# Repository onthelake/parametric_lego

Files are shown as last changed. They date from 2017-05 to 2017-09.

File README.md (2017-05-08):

# Parametric LEGO #

### 3D Printable LEGO shapes with fine-tuning parameters for a tight fit with different materials ###

Print out snap-together cases and objects by starting from a proper LEGO part. Making LEGO-compatibible boxes and enclosures is one of the motivations for this project. See for example https://github.com/paulirotta/lego_grove

### Who do I talk to? ###

* paulirotta@gmail.com
* https://twitter.com/mobile_rat
* https://medium.com/@paulhoughton
* https://github.com/paulirotta/parametric_lego/

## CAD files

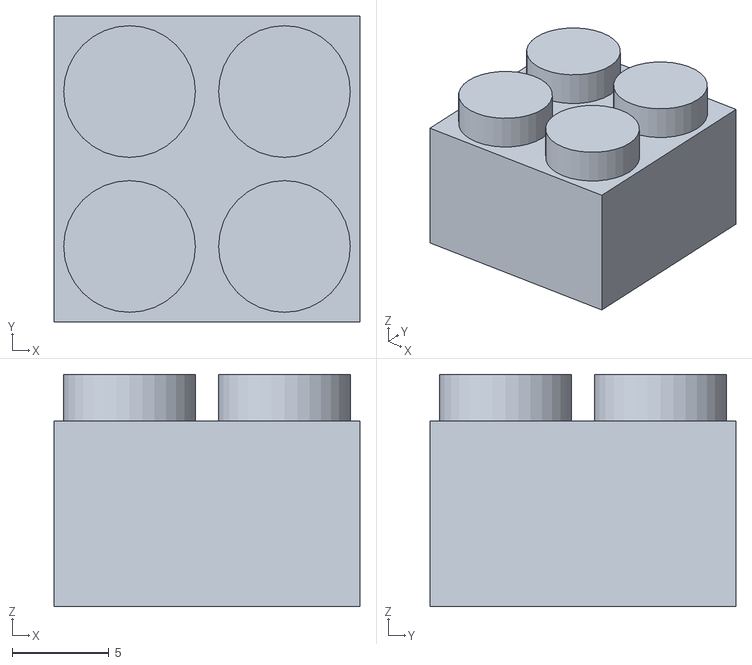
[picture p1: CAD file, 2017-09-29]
lego-abs-2x2x1.stl
15.8 x 15.8 x 12.0

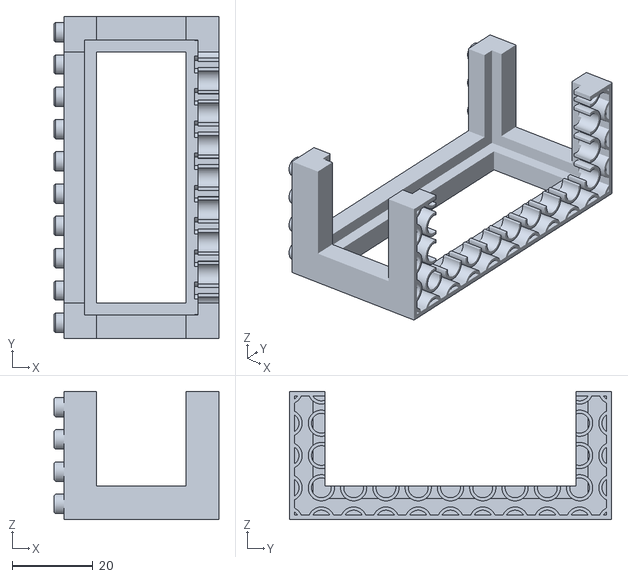
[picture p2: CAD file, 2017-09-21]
lego-enclosure/lego-enclosure-abs.stl
40.8 x 79.8 x 31.8

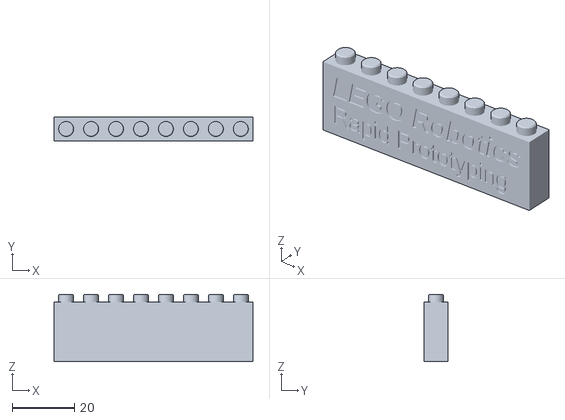
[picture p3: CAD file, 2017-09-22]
lego-sign/lego-sign-etched-abs.stl
63.8 x 7.80 x 21.6

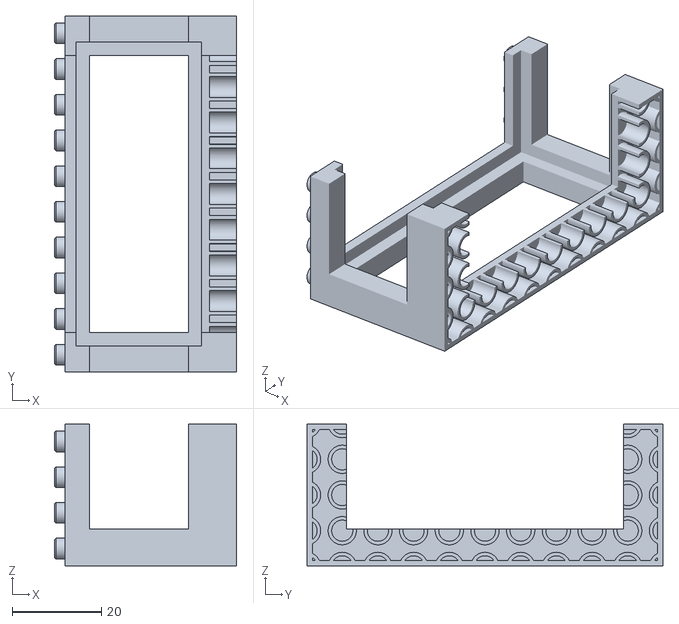
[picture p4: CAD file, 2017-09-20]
lego-enclosure/lego-enclosure-ngen.stl
40.8 x 79.8 x 31.8

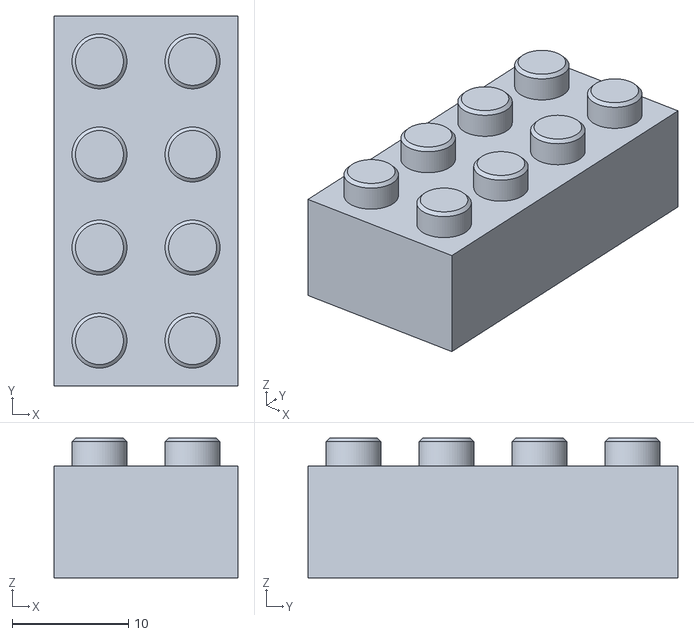
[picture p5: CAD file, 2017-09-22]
lego-pla-2x4x1.stl
15.8 x 31.8 x 12.0

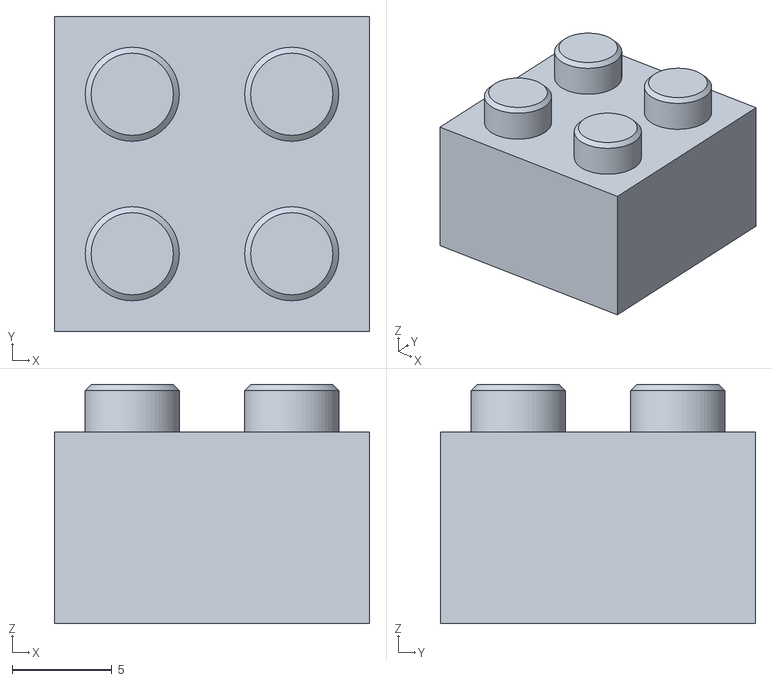
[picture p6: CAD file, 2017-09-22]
lego-pla-2x2x1.stl
15.8 x 15.8 x 12.0

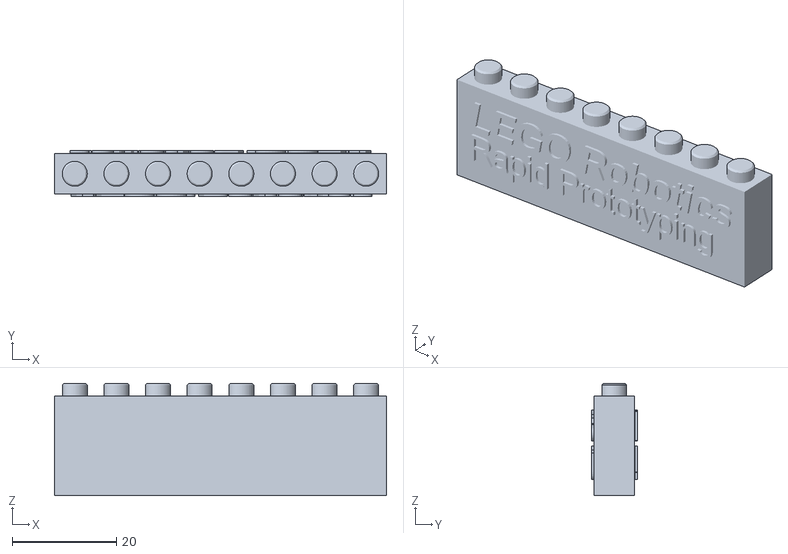
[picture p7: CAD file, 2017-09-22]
lego-sign/lego-sign-two-sided-abs.stl
63.8 x 8.90 x 21.6

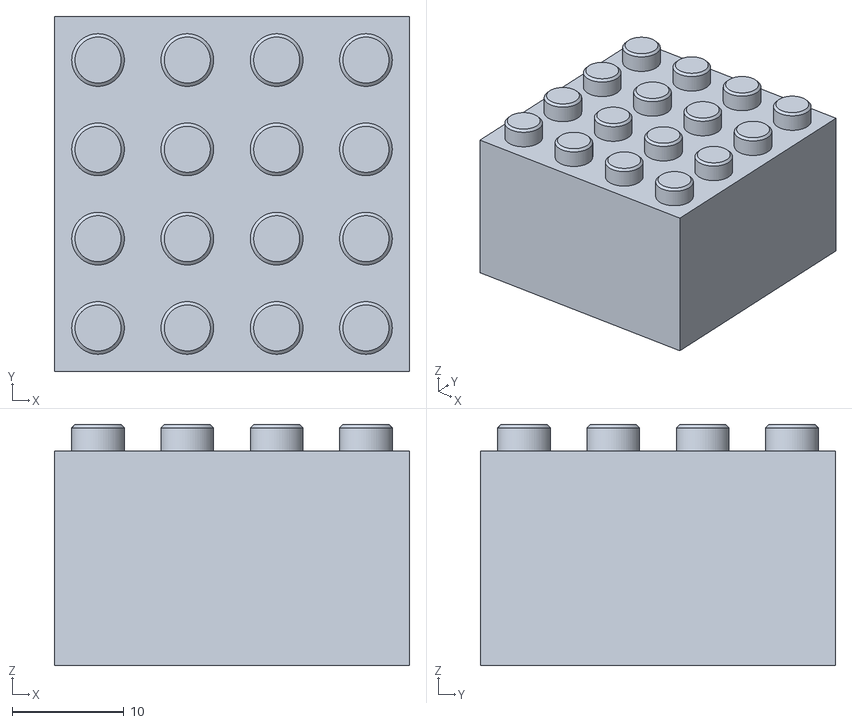
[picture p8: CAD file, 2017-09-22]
lego-pla-4x4x2.stl
31.8 x 31.8 x 21.6

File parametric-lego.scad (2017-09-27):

/*
Parametric LEGO Block

Published at
    http://www.thingiverse.com/thing:2303714
Maintained at
    https://github.com/paulirotta/parametric_lego
See also the related files
    LEGO Sign Generator - https://www.thingiverse.com/thing:2546028
    LEGO Enclosure Generator - https://www.thingiverse.com/thing:2544197


By Paul Houghton
Twitter: @mobile_rat
Email: paulirotta@gmail.com
Blog: https://medium.com/@paulhoughton

Creative Commons Attribution ShareAlike NonCommercial License
    https://creativecommons.org/licenses/by-sa/4.0/legalcode

Work sponsored by
    http://futurice.com

Import this into other design files:
    use <lego.scad>
*/

/* [LEGO Options plus Plastic and Printer Variance Adjustments] */

// What type of object to generate: "lego", "calibration", "panel"
mode="panel";

// How many Lego units wide the brick is
blocks_x = 15;

// How many Lego units long the brick is
blocks_y = 11;

// How many Lego units high the brick is
blocks_z = 1;


// Top connector size tweak => + = more tight fit, -0.04 for PLA, 0 for ABS, 0.07 for NGEN
top_tweak = 0.07;

// Bottom connector size tweak => + = more tight fit, 0.02 for PLA, 0 for ABS, -0.01 NGEN
bottom_tweak = -0.01;

// Number of facets to form a circle (big numbers are more round which affects fit, but may take a long time to render)
fn=64;

// Clearance space on the outer surface of bricks
skin = 0.1;

// Size of the connectors
knob_radius=2.4;

// Height of the connectors including any bevel (1.8 is Lego standard, longer gives a stronger hold which helps since 3D prints are less precise)
knob_height=2.4;

// Height of the easy connect slope near connector top (0 to disable is standard a slightly faster to generate the model, a bigger value such as 0.3 may help if you adjust a tight fit but most printers' slicers will simplify away most usable bevels)
knob_bevel=0;

// Size of the small cavity inside the connectors
knob_cutout_radius=1.25;

// Distance below knob top surface and the internal cutout
knob_top_thickness=1.25;

// Height of the cutout beneatch each knob
knob_cutout_height=4.35;

// Size of the hole to keep the cutout as part of the outside surface for slicer-friendliness. Enlarge this if you need to drain resin from the cutout.
knob_cutout_airhole_radius=0.01;

// Depth which connectors may press into part bottom
socket_height=6;

// Bottom connector assistance ring size
ring_radius=3.25;

// Bottom connector assistance ring thickness
ring_thickness=0.8;

// Basic unit horizonal size of LEGO
block_width=8;

// Basic unit vertial size of LEGO
block_height=9.6;

// Thickness of the solid outside surface of LEGO
block_shell=1.3; // thickness

// Lego panel height (flat back panel with screw holes in corners
cut_line=6.4;

// Font for calibration block text labels
font = "Arial";

// Text size on calibration blocks
font_size = 3.8;

// Depth of text labels on calibration blocks
text_extrusion_height = 0.5;

// Inset from block edge for text (vertical and horizontal)
text_margin = 1;

// Size between calibration block tweak test steps
calibration_block_increment = 0.01;

/////////////////////////////////////
// Test display, uncomment only one of the following lines at a time
/////////////////////////////////////

if (mode=="calibration") {
    lego_calibration_set(); // A set of blocks for testing which tweak parameters to use on your printer and plastic
} else if (mode=="panel") {
    lego_panel(); // A thin panel of knobs with a flat back and mounting screw holes in the corners, suitable for organizing projects
} else {
    lego(); // A single block
}

/////////////////////////////////////
// FUNCTIONS
/////////////////////////////////////

// Function for access to horizontal size from other modules
function lego_width(x=1) = x*block_width;

// Function for access to vertical size from other modules
function lego_height(z=1) = z*block_height;

// Function for access to outside shell size from other modules
function lego_shell_width() = block_shell;

// Function for access to clearance space from other modules
function lego_skin_width(i=1) = skin*i;

// Function for access to socket height from other modules
function lego_socket_height() = socket_height;

/////////////////////////////////////
// MODULES
/////////////////////////////////////

// A complete LEGO block, standard size, specify number of layers in X Y and Z
module lego(x=blocks_x, y=blocks_y, z=blocks_z, top_tweak=top_tweak, bottom_tweak=bottom_tweak, fn=fn) {
    difference() {
        union() {
            block_shell(x, y, z, fn);
            difference() {
                block_set(x, y, z, top_tweak, fn);
                socket_set(x, y, bottom_tweak, fn);
            }
        }
        skin(x, y, z);
    }
}


// Several blocks in a grid, one knob per block
module block_set(x=blocks_x, y=blocks_y, z=blocks_z, top_tweak=top_tweak, fn=fn) {
    for (i = [0:1:x-1]) {
        for (j = [0:1:y-1]) {
            translate([lego_width(i), lego_width(j), 0])
                block(z=z, top_size_tweak=top_tweak, knob_height=knob_height,knob_cutout_height=knob_cutout_height, knob_cutout_radius=knob_cutout_radius, knob_cutout_airhole_radius=knob_cutout_airhole_radius, fn=fn);
        }
    }
}


// The rectangular part of the the lego plus the knob
module block(z=bocks_z, top_tweak=top_tweak, knob_height=knob_height, knob_cutout_height=knob_cutout_height, knob_cutout_radius=knob_cutout_radius, knob_cutout_airhole_radius=knob_cutout_airhole_radius, fn=fn) {
    difference() {
        union() {
            cube([lego_width(), lego_width(), lego_height(z)]);
            translate([lego_width(0.5), lego_width(0.5), lego_height(z)])
                knob(top_tweak=top_tweak, knob_bevel=knob_bevel, fn=fn);
        }
        translate([lego_width(0.5), lego_width(0.5), lego_height(z)])
            knob_cutout(knob_height=knob_height, knob_cutout_height=knob_cutout_height, knob_cutout_radius=knob_cutout_radius, knob_cutout_airhole_radius=knob_cutout_airhole_radius, fn=fn);
    }
}


// The cylinder on top of a lego block
module knob(top_tweak=top_tweak, knob_bevel=knob_bevel, fn=fn) {
    cylinder(r=knob_radius+top_tweak, h=knob_height-knob_bevel, $fn=fn);
    if (knob_bevel > 0) {
        // This path is a bit slower, but does the same thing as the bath below for the most common case of knob_bevel==0
        translate([0, 0, knob_height-knob_bevel])
            intersection() {
                cylinder(r=knob_radius+top_tweak,h=knob_bevel, $fn=fn);
                cylinder(r1=knob_radius+top_tweak,r2=0,h=knob_radius+top_tweak, $fn=fn);
            }
    }
}


// The empty cylinder inside a knob
module knob_cutout(knob_height=knob_height, knob_cutout_height=knob_cutout_height, knob_cutout_radius=knob_cutout_radius, knob_cutout_airhole_radius=knob_cutout_airhole_radius, fn=fn) {
    cylinder(r=knob_cutout_airhole_radius, h=knob_height+0.1, $fn=fn);
    translate([0, 0, knob_height-knob_top_thickness-knob_cutout_height])
        cylinder(r=knob_cutout_radius, h=knob_cutout_height, $fn=fn);
}


// That solid outer skin of a block set
module block_shell(x=blocks_x, y=blocks_y, z=blocks_z) {
    cube([block_shell, lego_width(y), lego_height(z)]);
    translate([lego_width(x)-block_shell, 0, 0]) 
        cube([block_shell, lego_width(y), lego_height(z)]);
    
    cube([lego_width(x), block_shell, lego_height(z)]);
    translate([0, lego_width(y)-block_shell, 0])
        cube([lego_width(x), block_shell, lego_height(z)]);
    
    translate([0, 0, lego_height(z)-block_shell])
        cube([lego_width(x), lego_width(y), block_shell]);
}

// Bottom connector- negative space for one block
module socket(bottom_tweak=bottom_tweak, fn=fn) {
    difference() {
        cube([lego_width(), lego_width(), socket_height]);
        union() {
            socket_ring(bottom_tweak, fn);
            translate([lego_width(), 0, 0])
                socket_ring(bottom_tweak, fn);
            translate([0, lego_width(), 0]) 
                socket_ring(bottom_tweak, fn);
            translate([lego_width(), lego_width(), 0])
                socket_ring(bottom_tweak, fn);
        }
    }
}

// The circular bottom insert for attaching knobs
module socket_ring(bottom_tweak=bottom_tweak, fn=fn) {
    difference() {
        cylinder(r=ring_radius+bottom_tweak, h=socket_height, $fn=fn);
        cylinder(r=ring_radius+bottom_tweak-ring_thickness, h=socket_height, $fn=fn);
    }
}

// Bottom connector- negative space for multiple blocks
module socket_set(x=blocks_x, y=blocks_y, bottom_tweak=bottom_tweak, fn=fn) {
    for (i = [0:1:x-1]) {
        for (j = [0:1:y-1]) {
            translate([lego_width(i), lego_width(j), 0])
                socket(bottom_tweak, fn);
        }
    }
}
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

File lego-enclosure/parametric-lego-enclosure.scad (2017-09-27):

/*
Parametric LEGO End Cap Enclosure Generator

Create 2 symmetric end pieces which can support a solid object with LEGO-compatible attachment points on top and bottom. By printing only the end pieces instead of a complele enclosure, the print is minimized

Published at
    https://www.thingiverse.com/thing:2544197
Based on
    https://www.thingiverse.com/thing:2303714
Maintained at
    https://github.com/paulirotta/parametric_lego

By Paul Houghton
Twitter: @mobile_rat
Email: paulirotta@gmail.com
Blog: https://medium.com/@paulhoughton

Creative Commons Attribution ShareAlike NonCommercial License
    https://creativecommons.org/licenses/by-sa/4.0/legalcode

Work sponsored by
    http://futurice.com

Import this into other design files:
    use <anker-usb-lego-enclosure.scad>
*/

use <../lego.scad>

/* [LEGO Options plus Plastic and Printer Variance Adjustments] */

// How many Lego units wide the enclosure is
blocks_x = 23;

// How many Lego units long the enclosure is
blocks_y = 10;

// How many Lego units long is the enclosure holder
blocks_x_end_cap = 4;

// How many Lego units high the enclosure is
blocks_z = 4;

// Length of the object to be enclosed
enclosed_length = 173;

// Width of the object to be enclosed
enclosed_width = 68;

// Height of the object to be enclosed
enclosed_height = 28;

// Top connector size tweak => + = more tight fit, -0.04 for PLA, 0 for ABS, 0.07 for NGEN
top_tweak = 0;

// Bottom connector size tweak => + = more tight fit, 0.02 for PLA, 0 for ABS, -0.01 NGEN
bottom_tweak = 0;

// Number of facets to form a circle (big numbers are more round which affects fit, but may take a long time to render)
fn = 64;

// The size of the step in each corner which supports the enclosed part while providing ventilation holes to remove heat
shoulder = 3;

/////////////////////////////////////

// Test display
rotate([0,-90,0])
    lego_enclosure(top_tweak=top_tweak, bottom_tweak=bottom_tweak);

///////////////////////////////////


// A Lego brick with a hole inside to contain something of the specified dimensions
module lego_enclosure(l=enclosed_length, w=enclosed_width, h=enclosed_height, x=blocks_x, x_cap=blocks_x_end_cap, y=blocks_y, z=blocks_z, shoulder=shoulder, top_tweak=top_tweak, bottom_tweak=bottom_tweak, fn=fn) {
    
    // Add some margin to give space to fit the part
    skinned_l = l + lego_skin_width(2);
    skinned_w = w + lego_skin_width(2);
    skinned_h = h + lego_skin_width(2);
    
    // Inner box dimensions
    dl=(lego_width(x)-skinned_l)/2;
    dw=(lego_width(y)-skinned_w)/2;
    dh=(lego_height(z)-skinned_h)/2;
    
    difference() {
        lego(x=x_cap, y=y, z=z, top_tweak=top_tweak, bottom_tweak=bottom_tweak, fn=fn);
        translate([dl, dw, dh])
            enclosure_negative_space(skinned_l, skinned_w, skinned_h, shoulder);
    }
}

// Where to remove material to privide access for attachments and air ventilation
module enclosure_negative_space(l=enclosed_length, w=enclosed_width, h=enclosed_height, shoulder=shoulder) {
    ls = l - 2*shoulder;
    ws = w - 2*shoulder;
    hs = h - 2*shoulder;
    ls2 = ls+l;
    ws2 = ws+w;
    hs2 = hs+h;
    
    // Primary enclosure hole
    cube([l, w, h]);
    
    // Right air hole
    translate([l, shoulder, shoulder])
        cube([ls2, ws, hs]);
    
    // Left air hole
    translate([-ls2, shoulder, shoulder])
        cube([ls2, ws, hs]);
    
    // Back air hole
    translate([shoulder, w, shoulder])
        cube([ls, ws2, hs]);
        
    // Front air hole
    translate([shoulder, -ws2, shoulder])
        cube([ls, ws2, hs]);
        
    // Top air hole
    translate([shoulder, shoulder, h])
        cube([ls, ws, hs2]);
        
    // Bottom air hole
    translate([shoulder, shoulder, -hs2])
        cube([ls, ws, hs2]);
}

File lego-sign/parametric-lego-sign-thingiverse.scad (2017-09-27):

/*
Parametric LEGO End Cap Enclosure Generator

Create 2 symmetric end pieces which can support a solid object with LEGO-compatible attachment points on top and bottom. By printing only the end pieces instead of a complele enclosure, the print is minimized

Published at
    https://www.thingiverse.com/thing:2546028
Based on
    https://www.thingiverse.com/thing:2303714
Maintained at
    https://github.com/paulirotta/parametric_lego

By Paul Houghton
Twitter: @mobile_rat
Email: paulirotta@gmail.com
Blog: https://medium.com/@paulhoughton

Creative Commons Attribution ShareAlike NonCommercial License
    https://creativecommons.org/licenses/by-sa/4.0/legalcode

Work sponsored by
    http://futurice.com

Import this into other design files:
    use <parametric-lego-sign.scad>
    
NOTE: The online Thingiverse customizer does not support boolean variables, so
these variables have been changed to strings
*/

/* [LEGO Options plus Plastic and Printer Variance Adjustments] */

// The top line of text. Set to "" to not have any top line
text_line_1 = "LEGO Robotics";

// The second line of text
text_line_2 = "Rapid Prototyping";

// Language of the text
text_language = "en";

// The font to use for text on the top line
font_line_1 = "Liberation Sans:style=Bold Italic";

// The font to use for text on the bottom line
font_line_2 = "Arial";

// The font size (points) of the top line
font_size_line_1 = 5.8;

// The font size (points) of the top line
font_size_line_2 = 5;

// How deeply into the LEGO block to etch/extrude the text
text_extrusion_height = 0.5;

// Text is pushing out from the LEGO block. Set false to etch the text into the block
extrude = "false";

// Place the text on both sides
copy_to_back = "false";

// How many LEGO units wide the enclosure is
blocks_x = 8;

// How many LEGO units long the enclosure is
blocks_y = 1;

// How many LEGO units high the enclosure is
blocks_z = 2;

// Left corner horizontal position of the text
text_x_inset = 3;

// Bottom / top corner vertical position of the text
text_z_inset = 3;

// Top connector size tweak => + = more tight fit, -0.04 for PLA, 0 for ABS, 0.07 for NGEN
top_connector_tweak = 0;

// Bottom connector size tweak => + = more tight fit, 0.02 for PLA, 0 for ABS, -0.01 NGEN
bottom_connector_tweak = 0;

// Number of facets to form a circle (big numbers are more round which affects fit, but may take a long time to render)
rounding=32;

/////////////////////////////////////

// Test display
lego_sign();

///////////////////////////////////

// A LEGO brick with text on the side
module lego_sign(line_1=text_line_1, line_2=text_line_2, lang=text_language, e=extrude,  extrusion_height=text_extrusion_height, f1=font_line_1, f2=font_line_2, fs1=font_size_line_1, fs2=font_size_line_2, tx=text_x_inset, tz=text_z_inset, xb=blocks_x, yb=blocks_y, zb=blocks_z, bottom_size_tweak=bottom_connector_tweak, top_size_tweak=bottom_connector_tweak, fn=rounding) {
    if (e == "true") {
        lego(x=xb, y=yb, z=zb, bottomw_connector_tweak=bottom_size_tweak, top_connector_tweak=top_size_tweak, fn=fn);
        translate([lego_skin_width(), lego_skin_width(), lego_skin_width()])
            lego_sign_extruded_text(line_1, line_2, lang, extrusion_height, f1, f2, fs1, fs2, tx, tz, xb, yb, zb, bottom_size_tweak, top_size_tweak, fn);

        if (copy_to_back == "true") {
            translate([lego_skin_width()+lego_width(xb), lego_width(yb), lego_skin_width()])
                rotate([0, 0, 180])
                    lego_sign_extruded_text(line_1, line_2, lang, extrusion_height, f1, f2, fs1, fs2, tx, tz, xb, yb, zb, bottom_size_tweak, top_size_tweak, fn);
        }
    } else {
        difference() {
            lego(x=xb, y=yb, z=zb, bottom_connector_tweak=bottom_size_tweak, top_connector_tweak=top_size_tweak, fn=fn);
            union() {
                translate([lego_skin_width(), 0, lego_skin_width()])
                    lego_sign_etched_text(line_1, line_2, lang, extrusion_height+lego_skin_width(), f1, f2, fs1, fs2, tx, tz, xb, yb, zb, bottom_size_tweak, top_size_tweak, fn);

                    if (copy_to_back == "true") {
                         translate([lego_skin_width()+lego_width(xb), lego_skin_width()+lego_width(yb), lego_skin_width()])
                             rotate([0, 0, 180])
                                 lego_sign_etched_text(line_1, line_2, lang, extrusion_height+lego_skin_width(), f1, f2, fs1, fs2, tx, tz, xb, yb, zb, bottom_size_tweak, top_size_tweak, fn);
                    }
                }
            }
    }
}

// Two lines of text extruded out from the surface
module lego_sign_extruded_text(line_1=text_line_1, line_2=text_line_2, lang=text_language,  extrusion_height=text_extrusion_height, f1=font_line_1, f2=font_line_2, fs1=font_size_line_1, fs2=font_size_line_2, tx=text_x_inset, tz=text_z_inset, xb=blocks_x, yb=blocks_y, zb=blocks_z, bottom_size_tweak=bottom_connector_tweak, top_size_tweak=bottom_connector_tweak, fn=rounding) {
    translate([tx, 0, lego_height(zb)-tz])
        lego_text(txt=line_1, language=lang, font=f1, font_size=fs1, vertical_alignment="top");
    translate([tx, 0, tz])
        lego_text(txt=line_2, language=lang, font=f2, font_size=fs2, vertical_alignment="bottom");
}

// Two lines of text etched into the surface
module lego_sign_etched_text(line_1=text_line_1, line_2=text_line_2, lang=text_language,  extrusion_height=text_extrusion_height, f1=font_line_1, f2=font_line_2, fs1=font_size_line_1, fs2=font_size_line_2, tx=text_x_inset, tz=text_z_inset, xb=blocks_x, yb=blocks_y, zb=blocks_z, bottom_size_tweak=bottom_connector_tweak, top_size_tweak=bottom_connector_tweak, fn=rounding) {
    translate([tx, extrusion_height, lego_height(zb)-tz])
        lego_text(txt=line_1, l=lang, extrusion_height=extrusion_height, font=f1, font_size=fs1, vertical_alignment="top");
    translate([tx, extrusion_height, tz])
        lego_text(txt=line_2, l=lang, extrusion_height=extrusion_height, font=f2, font_size=fs2, vertical_alignment="baseline");
}

// Text for the side of calibration block prints
module lego_text(txt=text_line_1, l=text_language, extrusion_height=text_extrusion_height, font=font_line_1, font_size=font_size_line_1, vertical_alignment="bottom") {
    rotate([90,0,0])
        linear_extrude(height=extrusion_height)
            text(text=txt, language=l, font=font, size=font_size, halign="left", valign=vertical_alignment);
}



////// Partial copy of file lego.scad to make this a single file for use in thingiverse.com online generator

// Clearance space on the outer surface of bricks
skin = 0.1;

// Size of the connectors
knob_radius=2.4;

// Total height of the connectors (1.8 is Lego standard, longer gives a stronger hold which helps since 3D prints are less precise)
knob_height=2.4;

// Height of the easy connect slope near connector top (0 to disable, helps if you adjust a tight fit)
knob_bevel=0.3;

// Depth which connectors may press into part bottom
socket_height=6;

// Bottom connector assistance ring size
ring_radius=3.25;

// Bottom connector assistance ring thickness
ring_thickness=0.8;

// Basic unit horizonal size of LEGO
block_width=8;

// Basic unit vertial size of LEGO
block_height=9.6;

// Thickness of the solid outside surface of LEGO
block_shell=1.3; // thickness


/////////////////////////////////////

// The round bit on top of a lego block
module knob(top_size_tweak=0, fn=rounding) {
    $fn = fn;
    cylinder(r=knob_radius+top_size_tweak,h=knob_height-knob_bevel);
    translate([0,0,knob_height-knob_bevel]) 
        intersection() {
            cylinder(r=knob_radius+top_size_tweak,h=knob_bevel);
            cylinder(r1=knob_radius+top_size_tweak,r2=0,h=knob_radius+top_size_tweak);
        }
}

// The rectangular part of the the lego plus the knob
module block(z=1, top_size_tweak=0, fn=rounding) {
    cube([block_width,block_width,z*block_height]);
    translate([block_width/2,block_width/2,z*block_height])
        knob(top_size_tweak, fn);
}

// Several blocks in a grid, one knob per block
module block_set(x=2, y=2, z=2, top_size_tweak=0, fn=rounding) {
    for (i = [0:1:x-1]) {
        for (j = [0:1:y-1]) {
            translate([i*block_width,j*block_width,0])
                block(z, top_size_tweak, fn);
        }
    }
}

// That solid outer skin of the block set
module block_shell(x=2, y=2, z=2) {
    cube([block_shell,y*block_width,z*block_height]);
    translate([x*block_width-block_shell,0,0]) 
        cube([block_shell,y*block_width,z*block_height]);
    
    cube([x*block_width,block_shell,z*block_height]);
    translate([0,y*block_width-block_shell,0])
        cube([x*block_width,block_shell,z*block_height]);
    
    translate([0,0,z*block_height-block_shell])
        cube([x*block_width,y*block_width,block_shell]);
}
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

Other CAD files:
lego-sign/lego-sign-etched-ngen.stl
lego-enclosure/lego-enclosure-pla.stl
lego-sign/lego-sign-two-sided-ngen.stl
lego-ngen-2x4x1.stl
lego-sign/lego-sign-two-sided-pla.stl
lego-ngen-4x4x2.stl
lego-sign/lego-sign-etched-pla.stl
lego-ngen-2x2x1.stl
command-line-lego.scad
lego-sign/lego-sign.scad
lego.scad

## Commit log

2017-05-08 Comment updates
    [lego.scad]
2017-09-18 Added LEGO calibration block set for testing the parameters needed on a given printer and plastic to get a tight fit Added LEGO panel builder with corner screw holes Minor updates and tweaks Changed 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
    [lego-abs-2x2x1.stl, lego-abs-2x4x1.stl, lego-abs-4x4x2.stl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]
2017-09-19 Changed generic inner enclosure directory References to upper dir <lego.scad> Passing $fn as an argument into lego modules Enclosure now builds as an end
    TODO The skins on the bottom are not clean
    [enclosure.scad, lego.scad]
2017-09-19 Shape tuning- 4 blocks end cap to the enclosure
    [enclosure.scad, lego.scad]
2017-09-20 Updated the parametric Lego enclosure Fixed the Lego panel knob hole diameters More consistent use of default values in several places Added a Thingiverse customizer-compatible copy of the parametric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
    [USB-enclosure-ABS.stl, USB-enclosure-NGEN.stl, USB-enclosure-PLA.stl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]
2017-09-20 Added more generated STL files of pre-build variants Parametric LEGO Enclosure now references the correct thing numbers on Thingiverse
    [USB-enclosure-ABS.stl, USB-enclosure-NGEN.stl, USB-enclosure-PLA.stl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]
2017-09-20 Lego enclosure STL versions in the 90 degree rotation for printing orientation generated
    [lego-enclosure-abs.stl, lego-enclosure-ngen.stl, lego-enclosure-pla.stl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]
2017-09-20 Added parametric LEGO sign
    [lego-enclosure-abs.stl, lego-enclosure-ngen.stl, lego-enclosure-pla.stl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]
2017-09-21 Parametric sign has text properly centered Parametric sign taxt copy_to_back option added Parametric sign extrude and etch options supported
    [lego-enclosure-abs.stl, parametric-lego-enclosure-thingiverse.scad, parametric-lego-enclosure.scad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]
2017-09-21 Renamed the generated 2-sided ngen sign for consistency
    [parametric-lego-sign-abs.stl, parametric-lego-sign-etched-ngen.stl, parametric-lego-sign-etched-pla.stl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]
2017-09-21 Updated parametric sign online customizer to use string "true" instead of boolean Links in comments updated
    [lego.scad, parametric-lego-enclosure-thingiverse.scad, parametric-lego-enclosure.scad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]
2017-09-21 Test of string="true" for online customizer of the sign generator
    [parametric-lego-sign-thingiverse.scad]
2017-09-22 Updated the documented recommendation size for PLA More clear labeling of the size tweak variables
    [lego.scad, parametric-lego-enclosure-thingiverse.scad, parametric-lego-enclosure.scad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]
2017-09-22 Lower extrusion text depth for better ABS print quality (less likely to punch through the back due to print quality) Updated STLs generated by Parametric sign
    [parametric-lego-sign-etched-abs.stl, parametric-lego-sign-etched-ngen.stl, parametric-lego-sign-etched-pla.stl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]
2017-09-22 Calibration block are 2x2 with 10micron increments
    [lego.scad]
2017-09-22 Added PLA STL generation updates
    [lego-pla-2x2x1.stl, lego-pla-2x4x1.stl, lego-pla-4x4x2.stl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]
2017-09-25 Additional use of functions and parameters Added cutout below knobs
    [lego.scad]
2017-09-26 Added a hole below each knob to test flex of fit
    [lego.scad]
2017-09-26 Generated new calibration block .stl
    [lego.scad]
2017-09-27 Updates to simplify defaults in lego block Command line STL generator script (incomplete)
    [lego-abs-2x2x1.stl, lego-abs-2x4x1.stl, lego-abs-4x4x2.stl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]
2017-09-28 Renamed lego.scad -> parametric-lego.scad
    [parametric-lego-enclosure.scad, parametric-lego-sign.scad, parametric-lego.scad]
2017-09-29 Better through-hole under the knob Performance optimization, removing unneeded airole in panels etc More clear panel thickness parameter
    [command-line-lego.scad, lego-abs-2x2x1.stl, lego-sign-etched-abs.stl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]
2017-09-29 Small cleanup, removing test code and old parameters
    [lego.scad]
2017-09-29 Tune up
    [lego.scad]
2017-09-29 LEGO sign parameters updated to refelct full parameters of lego.scad
    [command-line-lego.scad, lego-sign.scad, lego.scad]
